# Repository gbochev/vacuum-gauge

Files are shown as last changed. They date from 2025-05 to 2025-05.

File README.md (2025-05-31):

# Vacuum gauge
Simple Arduino-based vacuum gauge for Pirani and Thermocouple sensor types

### Description
While developing a vacuum system used for homemade PVD sputtering aparatus I felt the need of a simple and cheap vacuum gauge that can measure pressures as low as 1 Pa. I was not able to find online a finished DIY project thus I created one. The main idea is to use a standard thermocouple sensor at first (some of them are expensive) and then try to transition to a simple Pirani type sensor which can even be a small lightbulb (the lightbulbs are commonly available and probably have relatively the same resistance and performance so once calibrated one can have very cheap sensor).

This project is still work in progress. Next steps will be to connect a thermocouple that has a datasheet (specifying the pressure in Pa and the mV output) interpolate the points from the datasheet and then place it into the arduino code. After that experiments with commonly available light bulbs can begin.
Since the lightbulbs (and some thermocouple gauges) need to operate under vacuum, two relays are added to stop the supply when the system is not under vacuum. 

### Tips
As some chinese Arduino clones do not have connected (or have them wrongly connected) protection diodes please be careful (or best advice - do not supply the board by the external supply and the USB at the same time) when you supply the board externally.

Mount all transistors and regulators on heatsinks as they will heat up during measurement.

Some cheap thermocouple gauges that I found are called: ЛТ-2 (LT-2) and ЛТ-4М (LT-4M). They can sometimes be found on ebay for a good price.

### Schematic
[You can view it here](vacuum_gauge.pdf)
### PCB
PCB is located in the pcb folder. It is created with KiCAD. You can order the PCB directly by using the production.zip (file that contains the exported gerber files).

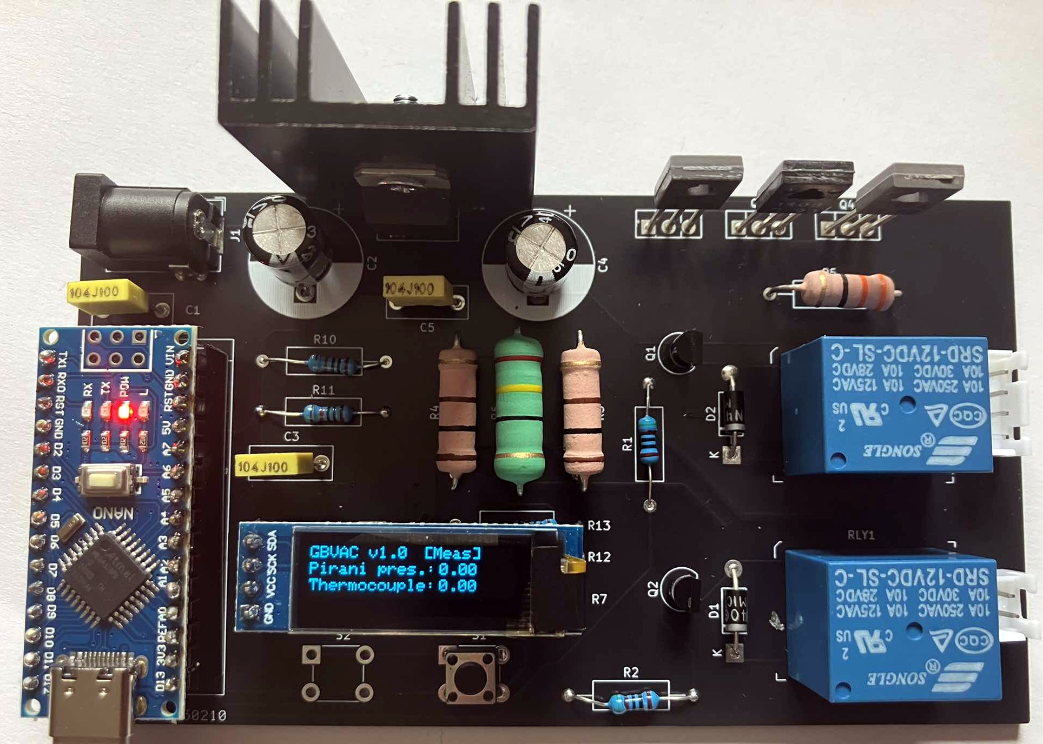
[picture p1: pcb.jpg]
PCB assembly


### Arduino code
The Arduino code is located in the arduino-code folder. The code still lacks the ability to measure pressure and it is a mess (I merged several online projects). It measures the pressure in mV. As next steps conversion tables for different sensor types will be added. In order to use it, please install the libraries (Adafruit and the others) that are referenced on the top of the file.

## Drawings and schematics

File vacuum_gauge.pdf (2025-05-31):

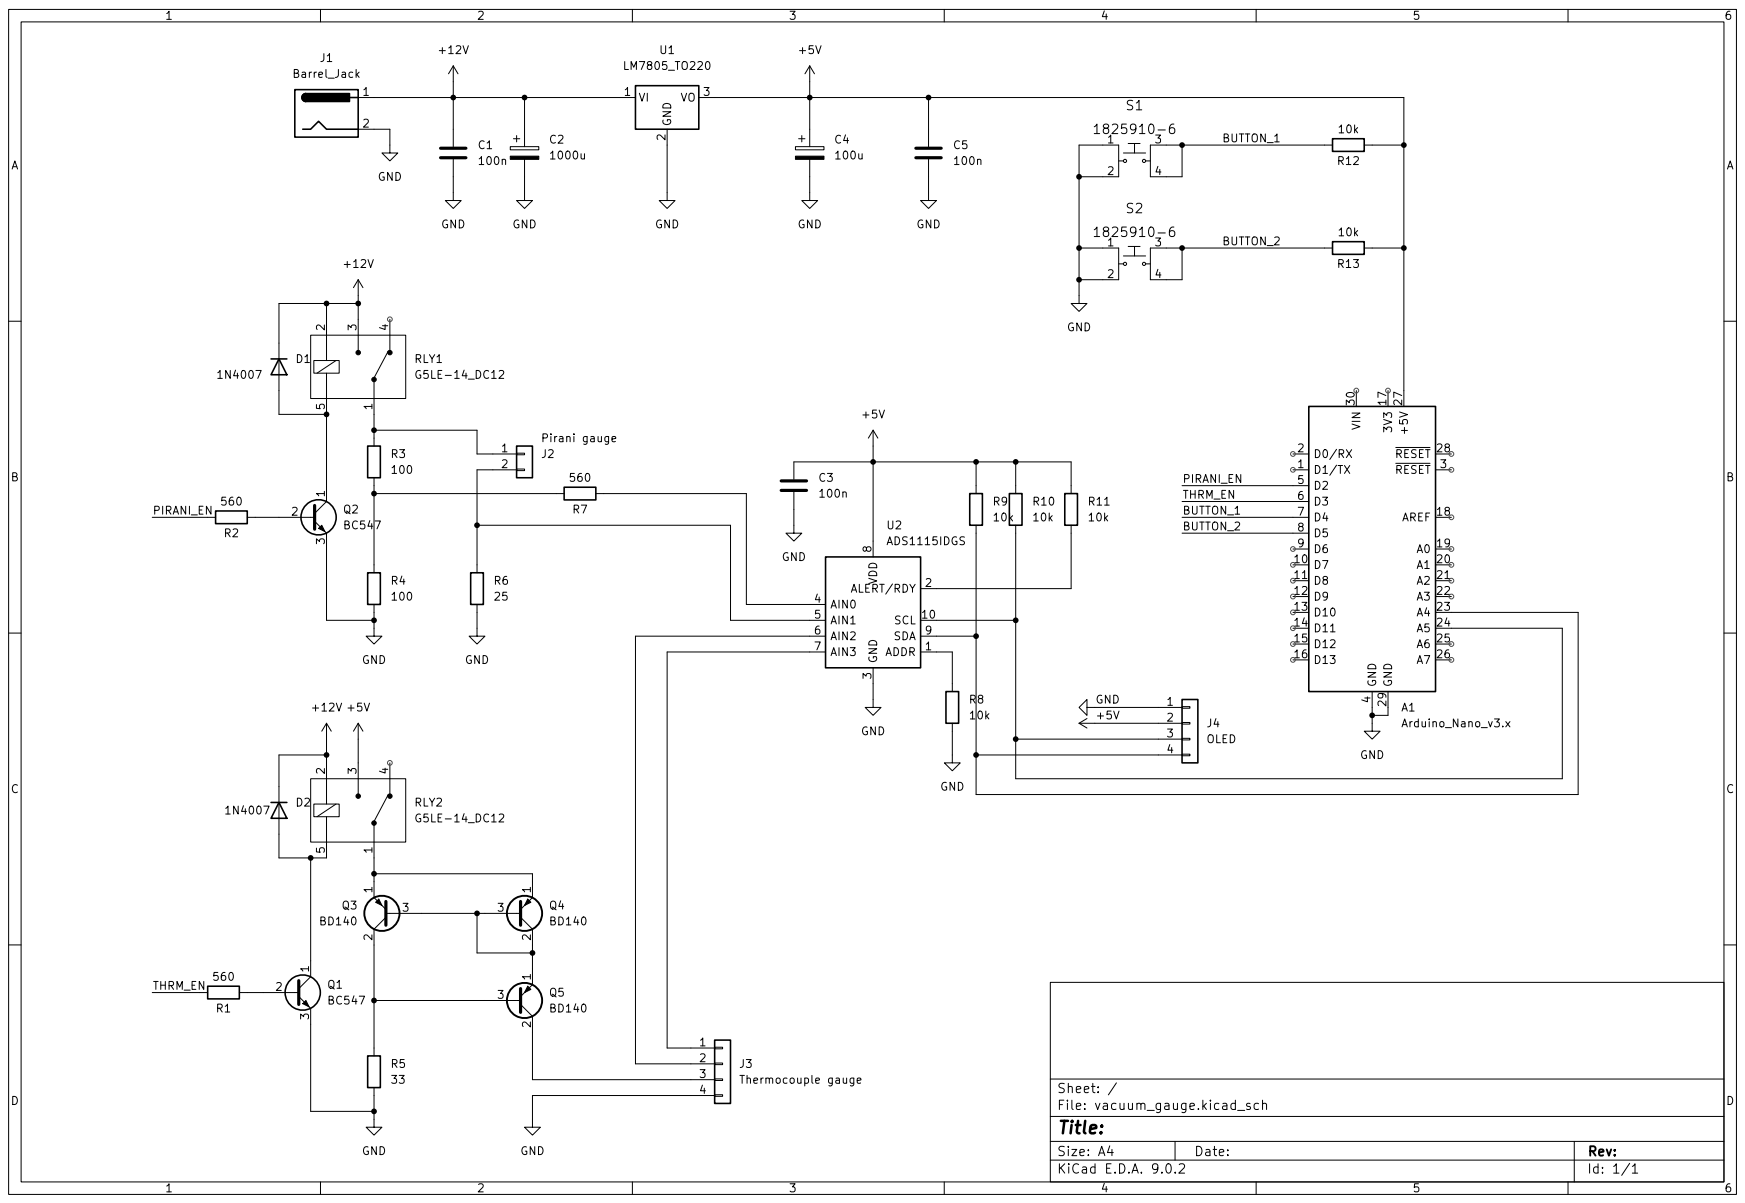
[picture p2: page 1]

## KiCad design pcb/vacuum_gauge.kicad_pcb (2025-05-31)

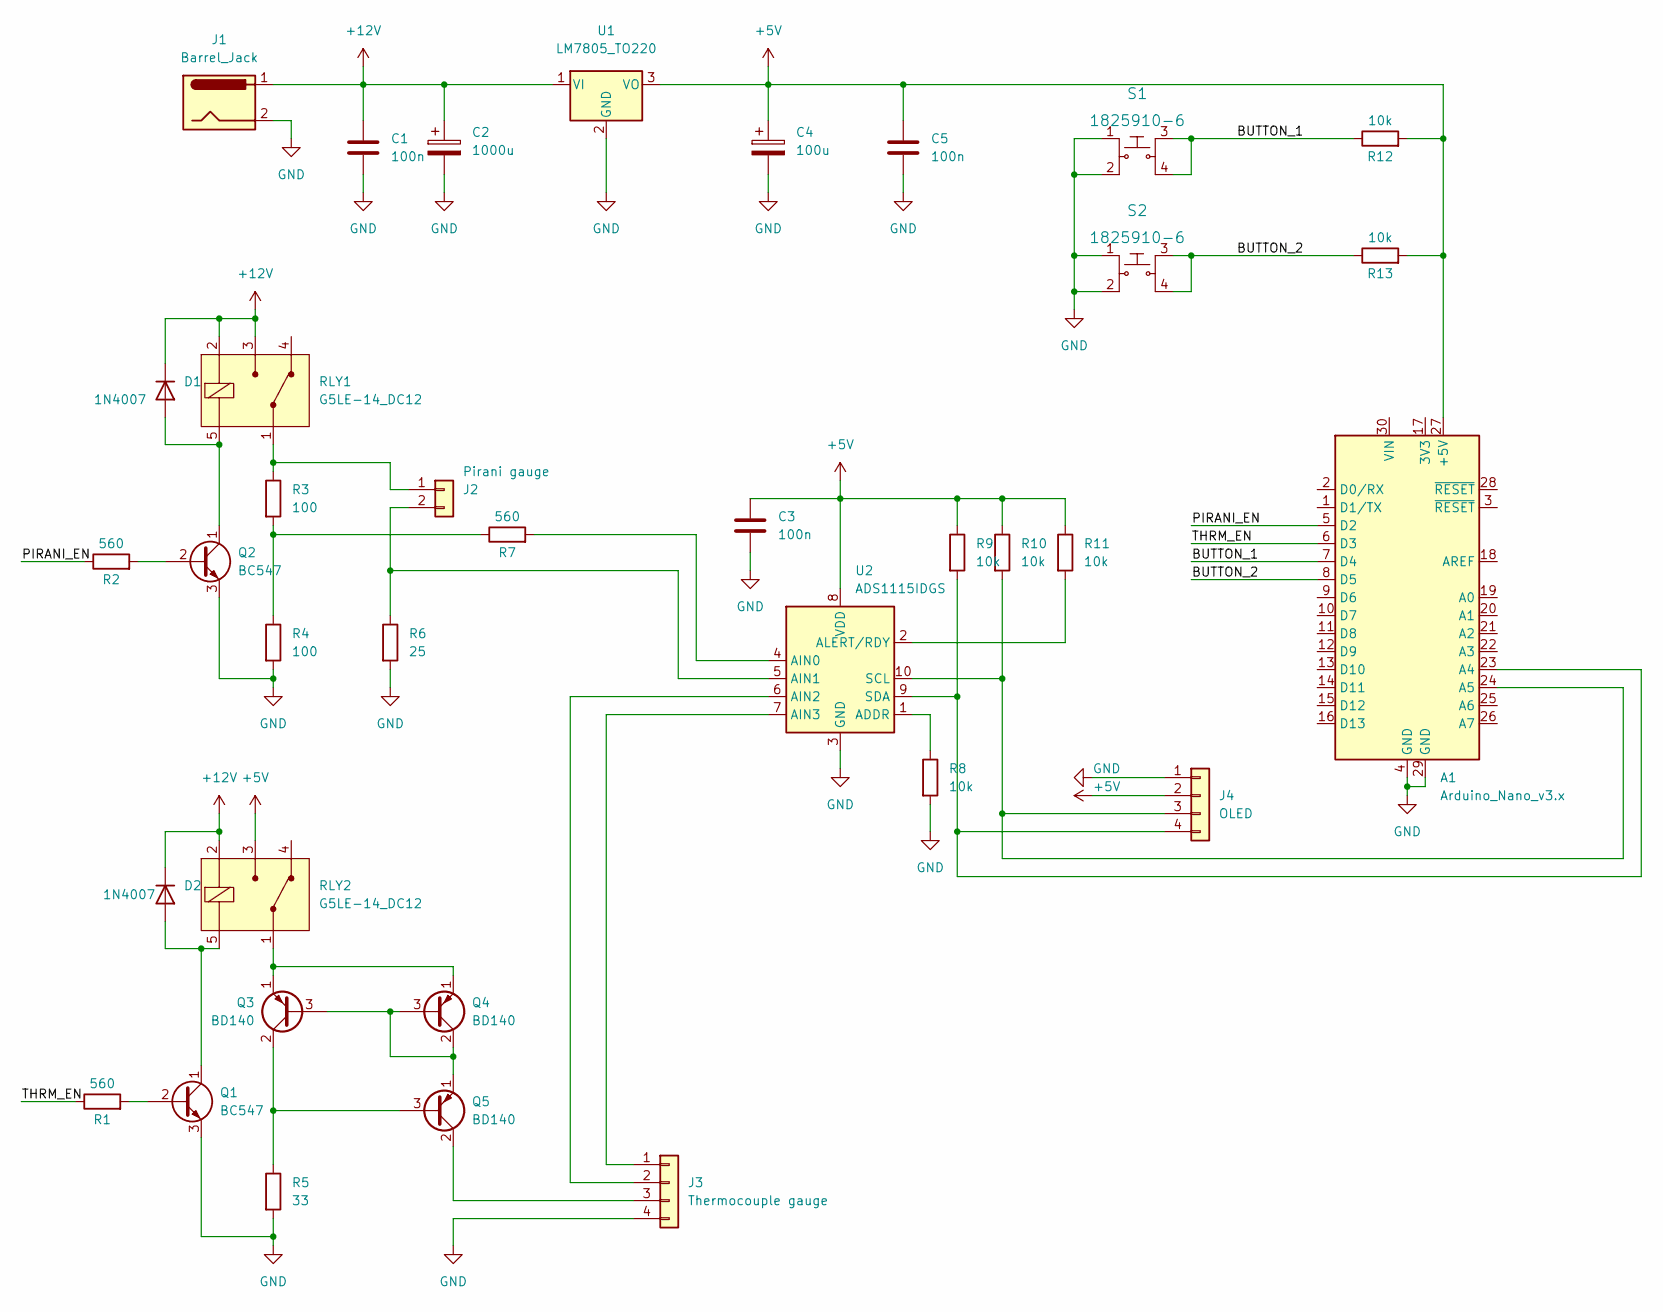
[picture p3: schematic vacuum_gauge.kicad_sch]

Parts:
A1: Arduino_Nano_v3.x; Arduino_Nano
C1, C3, C5: 100n; C_Rect_L10.0mm_W4.0mm_P7.50mm_MKS4
C2: 1000u; CP_Radial_D14.0mm_P7.50mm
C4: 100u; CP_Radial_D14.0mm_P7.50mm
D1, D2: 1N4007; D_DO-41_SOD81_P10.16mm_Horizontal
J1: Barrel_Jack; BarrelJack_GCT_DCJ200-10-A_Horizontal
J2: Pirani gauge; PinHeader_1x02_P2.54mm_Vertical
J3: Thermocouple gauge; PinHeader_1x04_P2.54mm_Vertical
J4: OLED; PinHeader_1x04_P2.54mm_Vertical
Q1, Q2: BC547; TO-92_Inline
Q3, Q4, Q5: BD140; TO-126-3_Vertical
R1, R2, R7: 560; R_Axial_DIN0309_L9.0mm_D3.2mm_P15.24mm_Horizontal
R3, R4: 100; R_Axial_DIN0309_L9.0mm_D3.2mm_P15.24mm_Horizontal
R5: 33; R_Axial_DIN0309_L9.0mm_D3.2mm_P15.24mm_Horizontal
R6: 25; R_Axial_DIN0309_L9.0mm_D3.2mm_P15.24mm_Horizontal
R8, R9, R10, R11, R12, R13: 10k; R_Axial_DIN0309_L9.0mm_D3.2mm_P15.24mm_Horizontal
RLY1, RLY2: G5LE-14_DC12; Relay_THT_G5LE-14; MPN G5LE-14 DC12; Digi-Key_PN Z1012-ND
S1, S2: 1825910-6; Switch_Tactile_THT_6x6mm; MPN 1825910-6; Digi-Key_PN 450-1650-ND
U1: LM7805_TO220; TO-220-3_Vertical
U2: ADS1115IDGS; TSSOP-10_3x3mm_P0.5mm

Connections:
+5V: A1.27 (+5V), C3.1, C4.1, C5.1, J4.2, R9.1, R10.1, R11.1, R12.2, R13.2, RLY2.3 (NO), U1.3 (VO), U2.8 (VDD)
+12V: C1.1, C2.1, D1.1 (K), D2.1 (K), J1.1, RLY1.2 (COIL), RLY1.3 (NO), RLY2.2 (COIL), U1.1 (VI)
/BUTTON_1: A1.7 (D4), R12.1, S1.3, S1.4
/BUTTON_2: A1.8 (D5), R13.1, S2.3, S2.4
/PIRANI_EN: A1.5 (D2), R2.1
/THRM_EN: A1.6 (D3), R1.1
GND: A1.4 (GND), A1.29 (GND), C1.2, C2.2, C3.2, C4.2, C5.2, J1.2, J3.4, J4.1, Q1.3 (E), Q2.3 (E), R4.2, R5.2, R6.2, R8.2, S1.1, S1.2, S2.1, S2.2, U1.2 (GND), U2.3 (GND)
unnamed: A1.23 (A4), J4.4, R9.2, U2.9 (SDA)
unnamed: A1.24 (A5), J4.3, R10.2, U2.10 (SCL)
unnamed: D1.2 (A), Q2.1 (C), RLY1.5 (COIL)
unnamed: D2.2 (A), Q1.1 (C), RLY2.5 (COIL)
unnamed: J2.1, R3.1, RLY1.1 (COM)
unnamed: J2.2, R6.1, U2.5 (AIN1)
unnamed: J3.1, U2.7 (AIN3)
unnamed: J3.2, U2.6 (AIN2)
unnamed: J3.3, Q5.2 (C)
unnamed: Q1.2 (B), R1.2
unnamed: Q2.2 (B), R2.2
unnamed: Q3.1 (E), Q4.1 (E), RLY2.1 (COM)
unnamed: Q3.2 (C), Q5.3 (B), R5.1
unnamed: Q3.3 (B), Q4.2 (C), Q4.3 (B), Q5.1 (E)
unnamed: R3.2, R4.1, R7.1
unnamed: R7.2, U2.4 (AIN0)
unnamed: R8.1, U2.1 (ADDR)
unnamed: R11.2, U2.2 (ALERT/RDY)

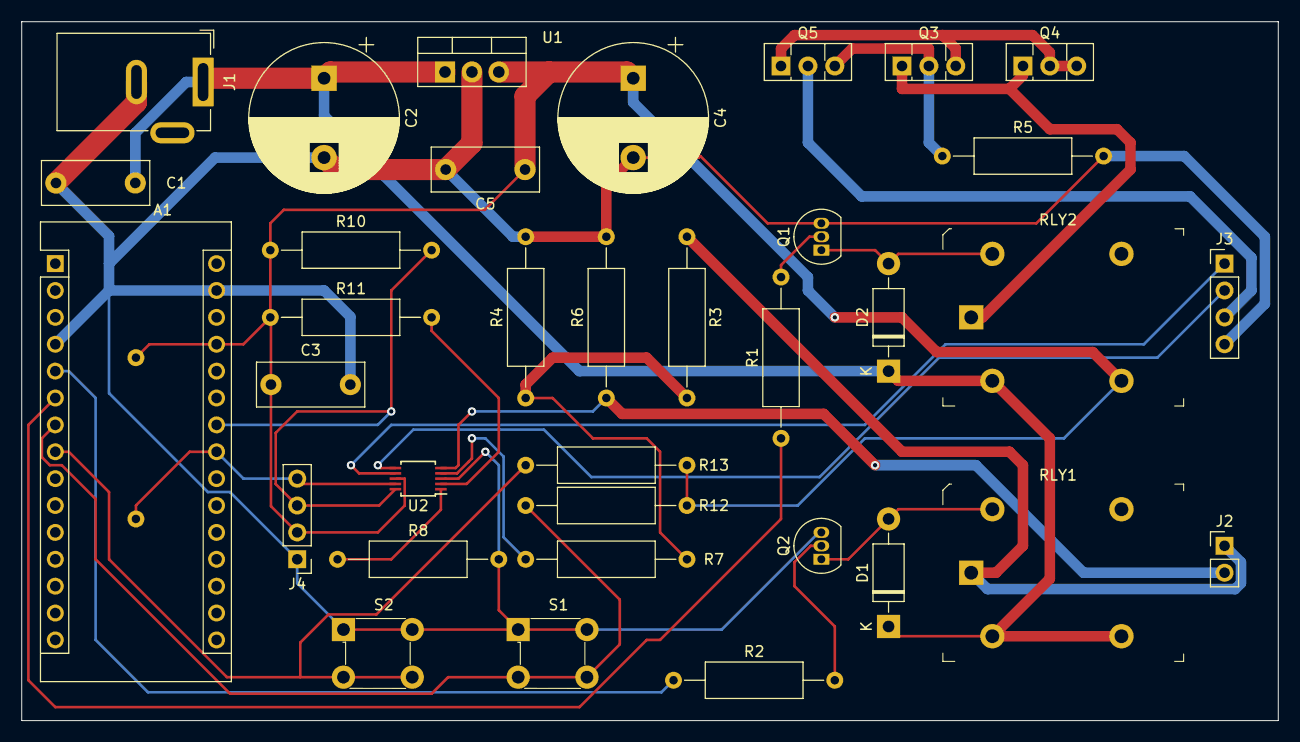
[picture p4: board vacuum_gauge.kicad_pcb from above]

Board: 2 copper layers, 118.7 x 66.0 mm, 36 parts (1 on the bottom side), 25 nets.

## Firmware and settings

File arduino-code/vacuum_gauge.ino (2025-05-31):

#include <SPI.h>
#include <Wire.h>
#include <Adafruit_GFX.h>
#include <Adafruit_SSD1306.h>
#include <Adafruit_ADS1X15.h>
#include <Button.h>

#define SCREEN_WIDTH 128 // OLED display width, in pixels
#define SCREEN_HEIGHT 32 // OLED display height, in pixels
#define OLED_RESET     -1 // Reset pin # (or -1 if sharing Arduino reset pin)
#define SCREEN_ADDRESS 0x3C ///< See datasheet for Address; 0x3D for 128x64, 0x3C for 128x32
// Declaration for an SSD1306 display connected to I2C (SDA, SCL pins)
// The pins for I2C are defined by the Wire-library. 
// On an arduino UNO:       A4(SDA), A5(SCL)

const int button1_pin = 4;
const int button2_pin = 5;
const int pirani_en_pin = 2; 
const int thrm_en_pin = 3; 

Adafruit_SSD1306 display(SCREEN_WIDTH, SCREEN_HEIGHT, &Wire, OLED_RESET);
Adafruit_ADS1115 ads;

Button button1(button1_pin); // Connect your button between pin 2 and GND
Button button2(button2_pin); // Connect your button between pin 3 and GND

bool measurement_active = false;

void setup() {

  pinMode(pirani_en_pin, OUTPUT);
  pinMode(thrm_en_pin, OUTPUT);
  //stop the relays (if they were set to 1)
  digitalWrite(pirani_en_pin, LOW);
  digitalWrite(thrm_en_pin, LOW);

  button1.begin();
	button2.begin();

  Serial.begin(9600);

  // SSD1306_SWITCHCAPVCC = generate display voltage from 3.3V internally
  if(!display.begin(SSD1306_SWITCHCAPVCC, SCREEN_ADDRESS)) {
    Serial.println(F("SSD1306 allocation failed"));
    for(;;); // Don't proceed, loop forever
  }

  if (!ads.begin()) {
    Serial.println("Failed to initialize ADS.");
    while (1);
  }

  delay(2000);
  display.clearDisplay();

  display.setTextSize(1);
  display.setTextColor(WHITE);
  display.setCursor(0, 0);
  display.println("Vacuum gauge v1.0");
  display.display(); 

}

void loop() {
  int16_t ads_0_results = 0; //A0-A1 diff
  int16_t ads_1_results = 0; //A2-A3 diff
  float multiplier = 0.1875F; /* ADS1115  @ +/- 6.144V gain (16-bit results) */

  if (measurement_active){
    ads_0_results = ads.readADC_Differential_0_1();
    ads_1_results = ads.readADC_Differential_2_3();
  }

  //display data
  display.clearDisplay();
  display.setTextSize(1);
  display.setTextColor(WHITE);
  display.setCursor(0, 0);
  display.println("GBVAC v1.0");
  display.setCursor(0, 10);
  display.println("Pirani pres.:");
  display.setCursor(80, 10);
  display.println(ads_0_results * multiplier);
  display.setCursor(0, 20);
  display.println("Thermocouple:");
  display.setCursor(80, 20);
  display.println(ads_1_results * multiplier);
  display.setCursor(70, 0);
  if (!measurement_active)
    display.println("[Stopped]");
  else
    display.println("[Meas]");
  display.display(); 

  if (button1.pressed()) {
    measurement_active = !measurement_active;
    if (measurement_active){
      digitalWrite(pirani_en_pin, HIGH);
      digitalWrite(thrm_en_pin, HIGH);
    } else {
      digitalWrite(pirani_en_pin, LOW);
      digitalWrite(thrm_en_pin, LOW);
    }
  }

}

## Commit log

2025-05-31 Add files via upload
    Initial commit
    [vacuum_gauge.kicad_pcb, vacuum_gauge.kicad_sch]
2025-05-31 Update and rename vacuum_gauge.kicad_sch to pcb/vacuum_gauge.kicad_sch
    [vacuum_gauge.kicad_sch]
2025-05-31 Update and rename vacuum_gauge.kicad_pcb to pcb/vacuum_gauge.kicad_pcb
    [vacuum_gauge.kicad_pcb]
